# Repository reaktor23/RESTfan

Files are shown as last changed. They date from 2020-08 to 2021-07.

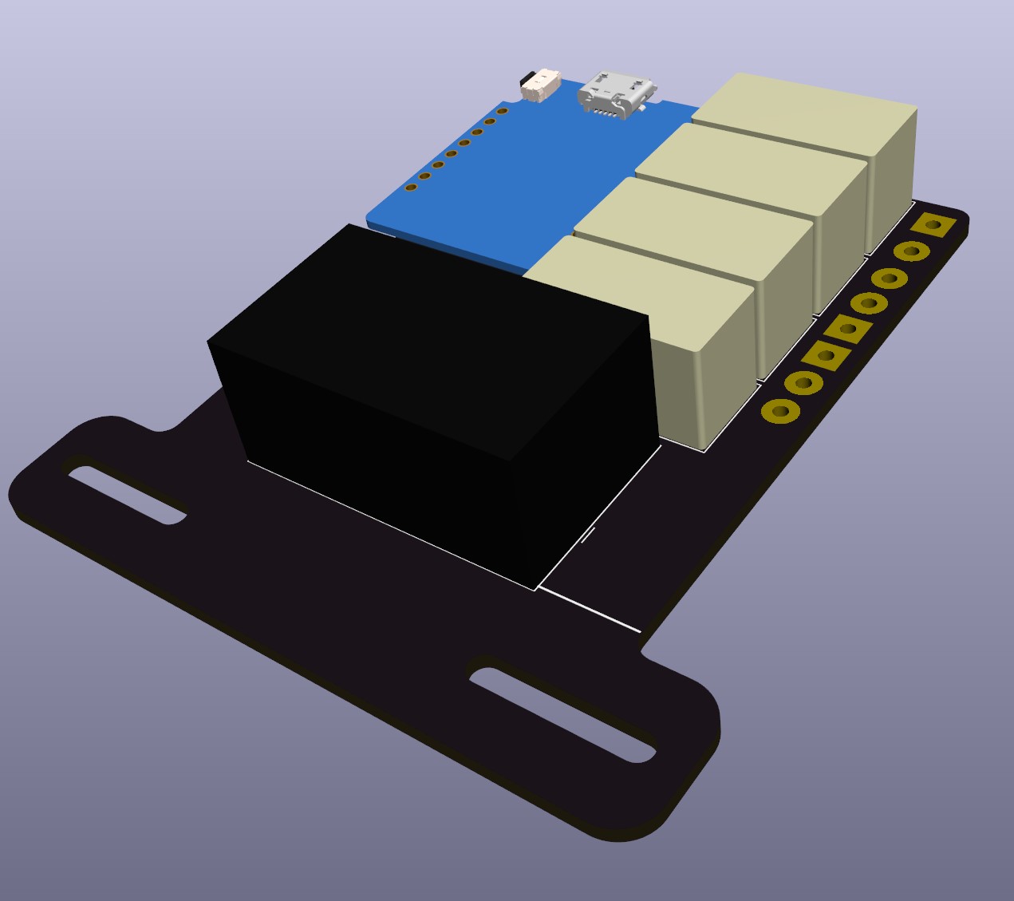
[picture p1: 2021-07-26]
Top.jpg

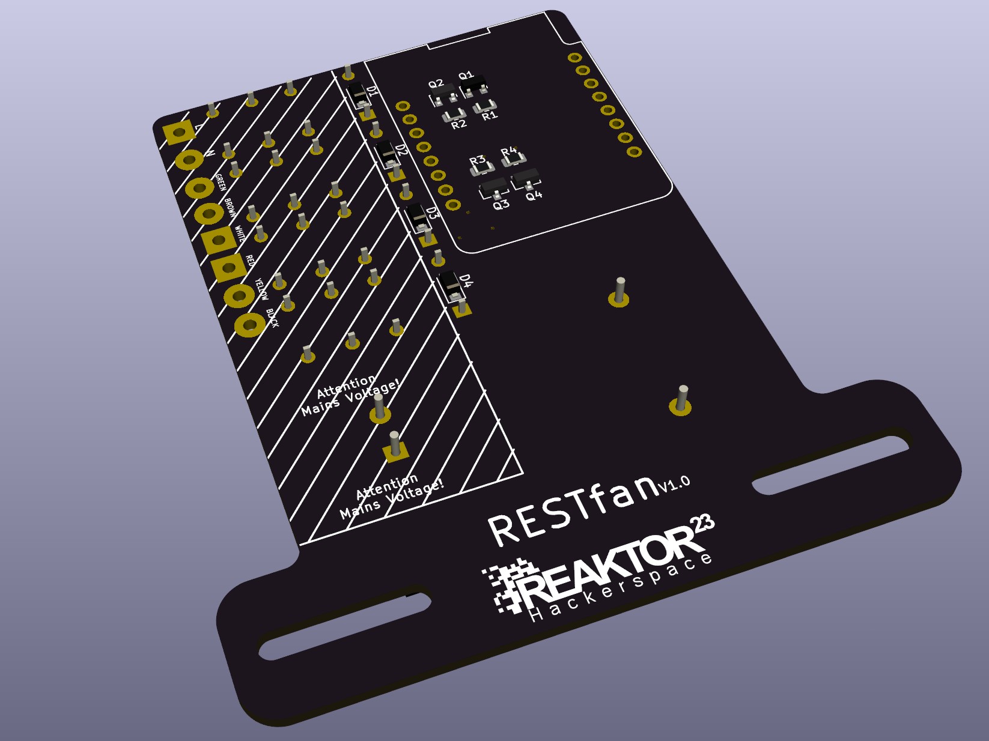
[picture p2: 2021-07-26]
Bottom.jpg

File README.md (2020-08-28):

# RESTfan

A REST controllable wall fan

We bought a cheap wall mount fan which had pull strings for control. Big no no for a Hackerspace :sunglasses:

So we created a small PCB with a 230VAC to 5VDC converter, a Wemos D1 mini and 4 relays on it that allows us to control the fan over a REST API.

# Hardware

The fan is a [Tristar VE-5874 wall mount ventilator](https://www.tristar.eu/de-de/tristar-ve-5874-wandventilator-ve--5874)

# API

- `http://<ip>/off` Fan and oscillation off
- `http://<ip>/state` JSON object with the current state

## Speed control

 - `http://<ip>/speed/1` Fan speed 1
 - `http://<ip>/speed/2` Fan speed 2
 - `http://<ip>/speed/3` Fan speed 3

## Oscillation

 - `http://<ip>/oscillation/on` Oscillation on
 - `http://<ip>/oscillation/off` Oscillation off

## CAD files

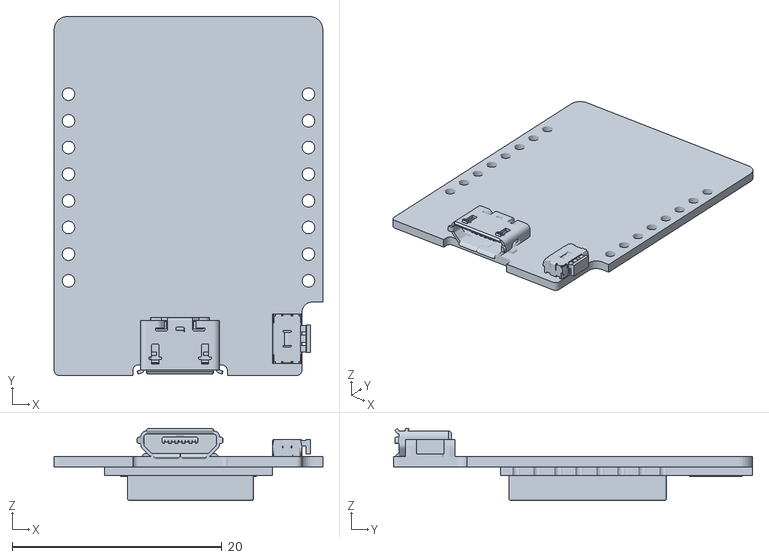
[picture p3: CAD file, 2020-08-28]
KiCAD/RESTfan/3Dshapes/wemos d1 mini.stl
25.6 x 34.2 x 6.90

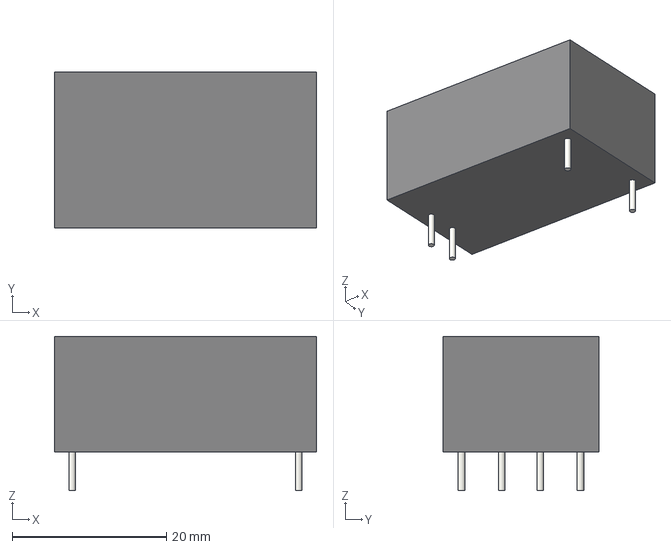
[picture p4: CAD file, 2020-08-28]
KiCAD/RESTfan/3Dshapes/Converter_ACDC_HiLink_HLK-PMxx.step
34.0 x 20.2 x 20.0 mm

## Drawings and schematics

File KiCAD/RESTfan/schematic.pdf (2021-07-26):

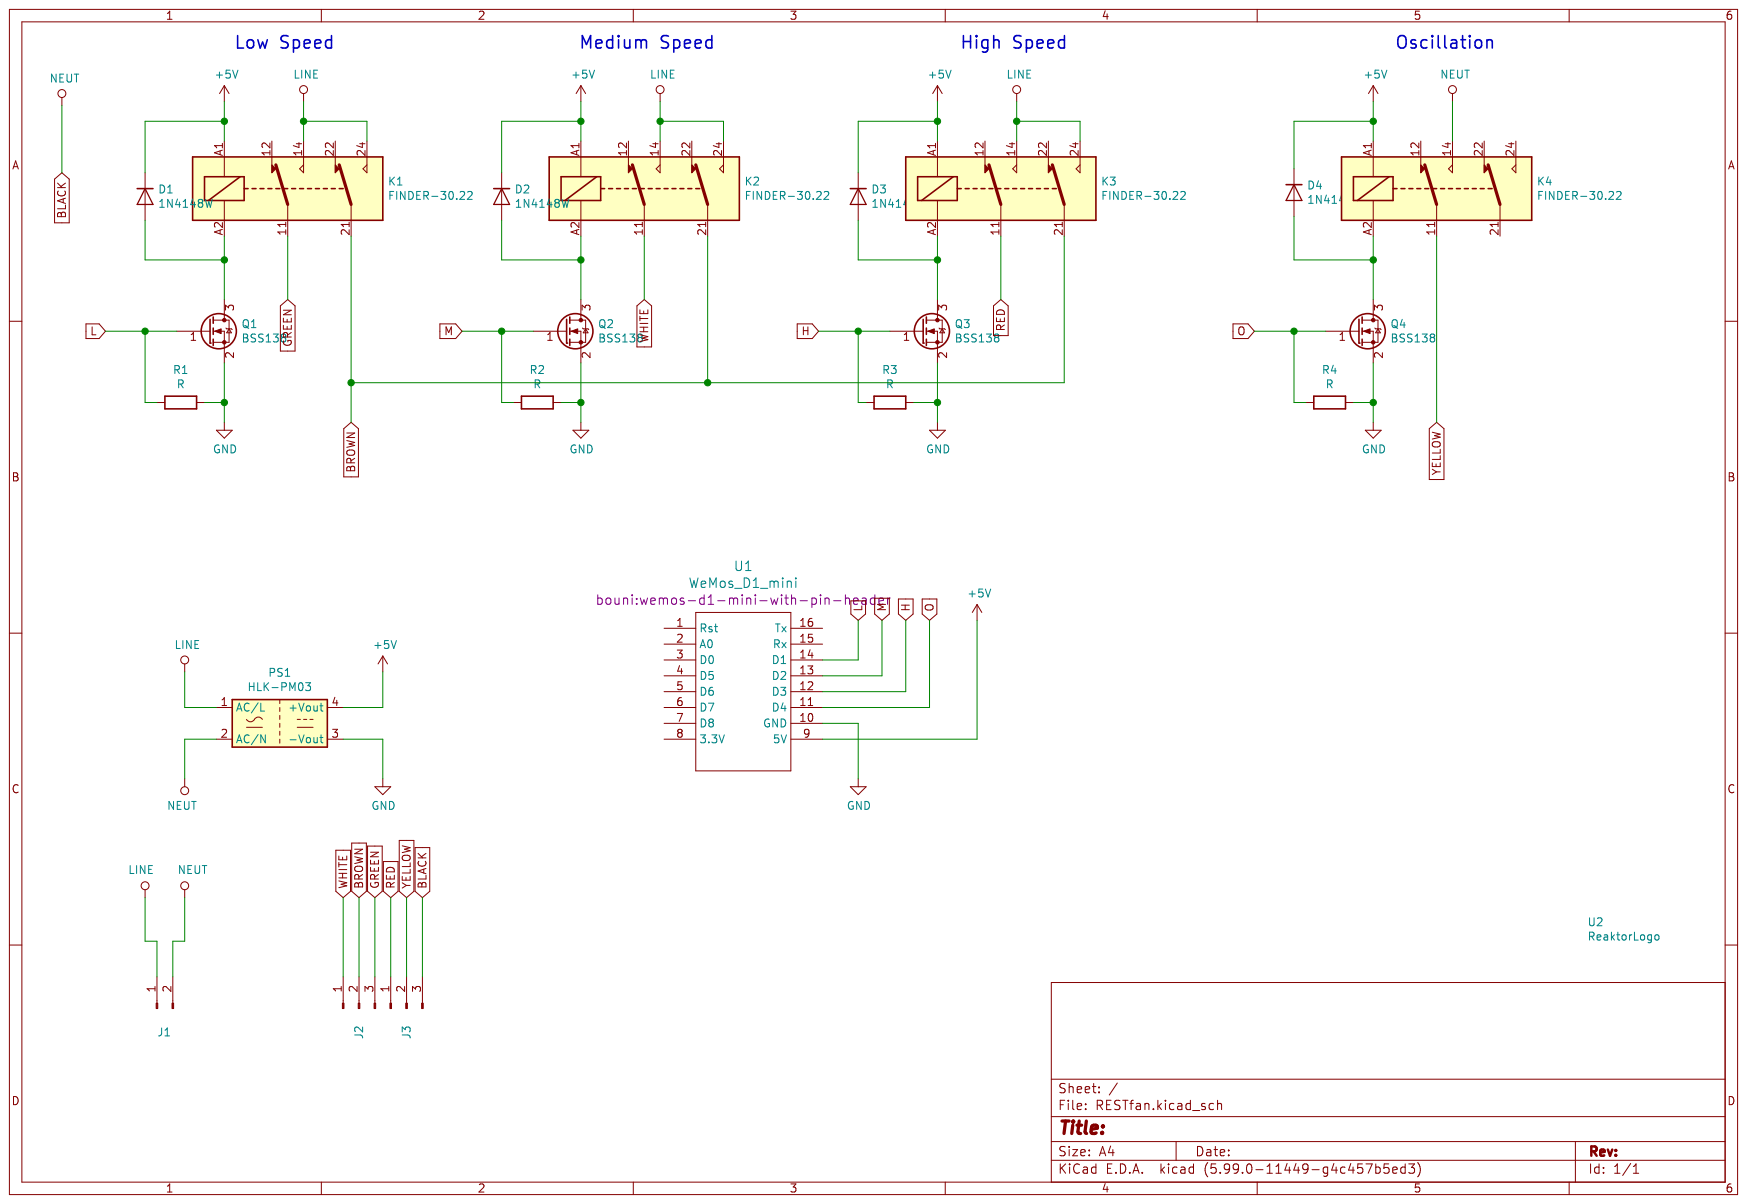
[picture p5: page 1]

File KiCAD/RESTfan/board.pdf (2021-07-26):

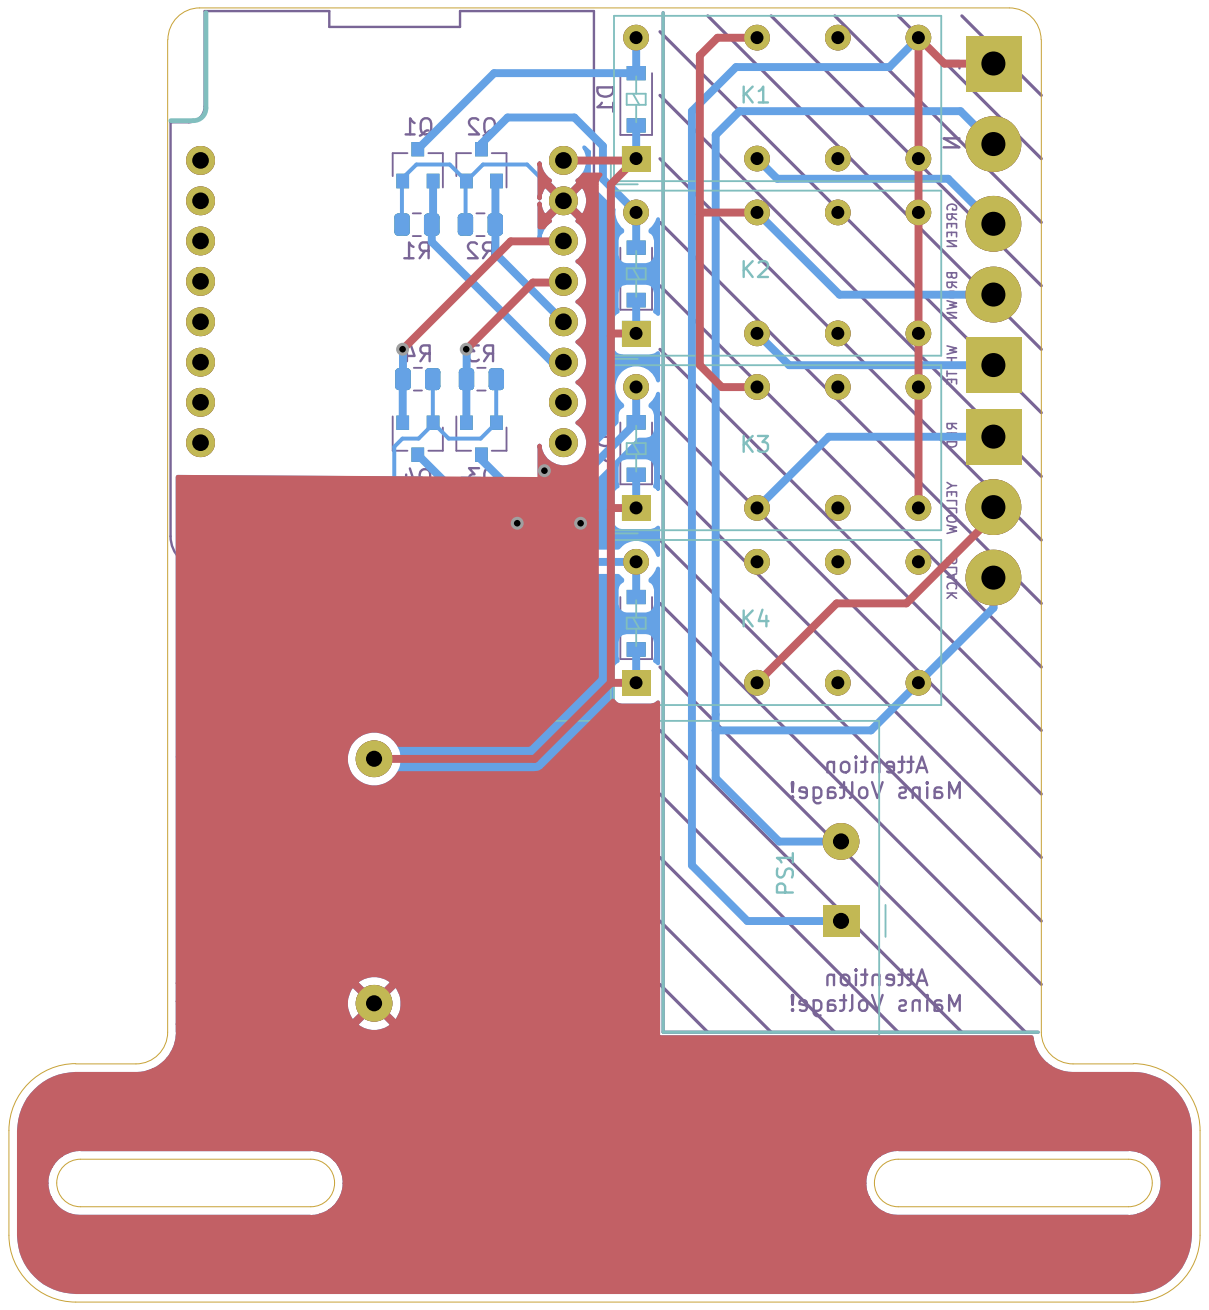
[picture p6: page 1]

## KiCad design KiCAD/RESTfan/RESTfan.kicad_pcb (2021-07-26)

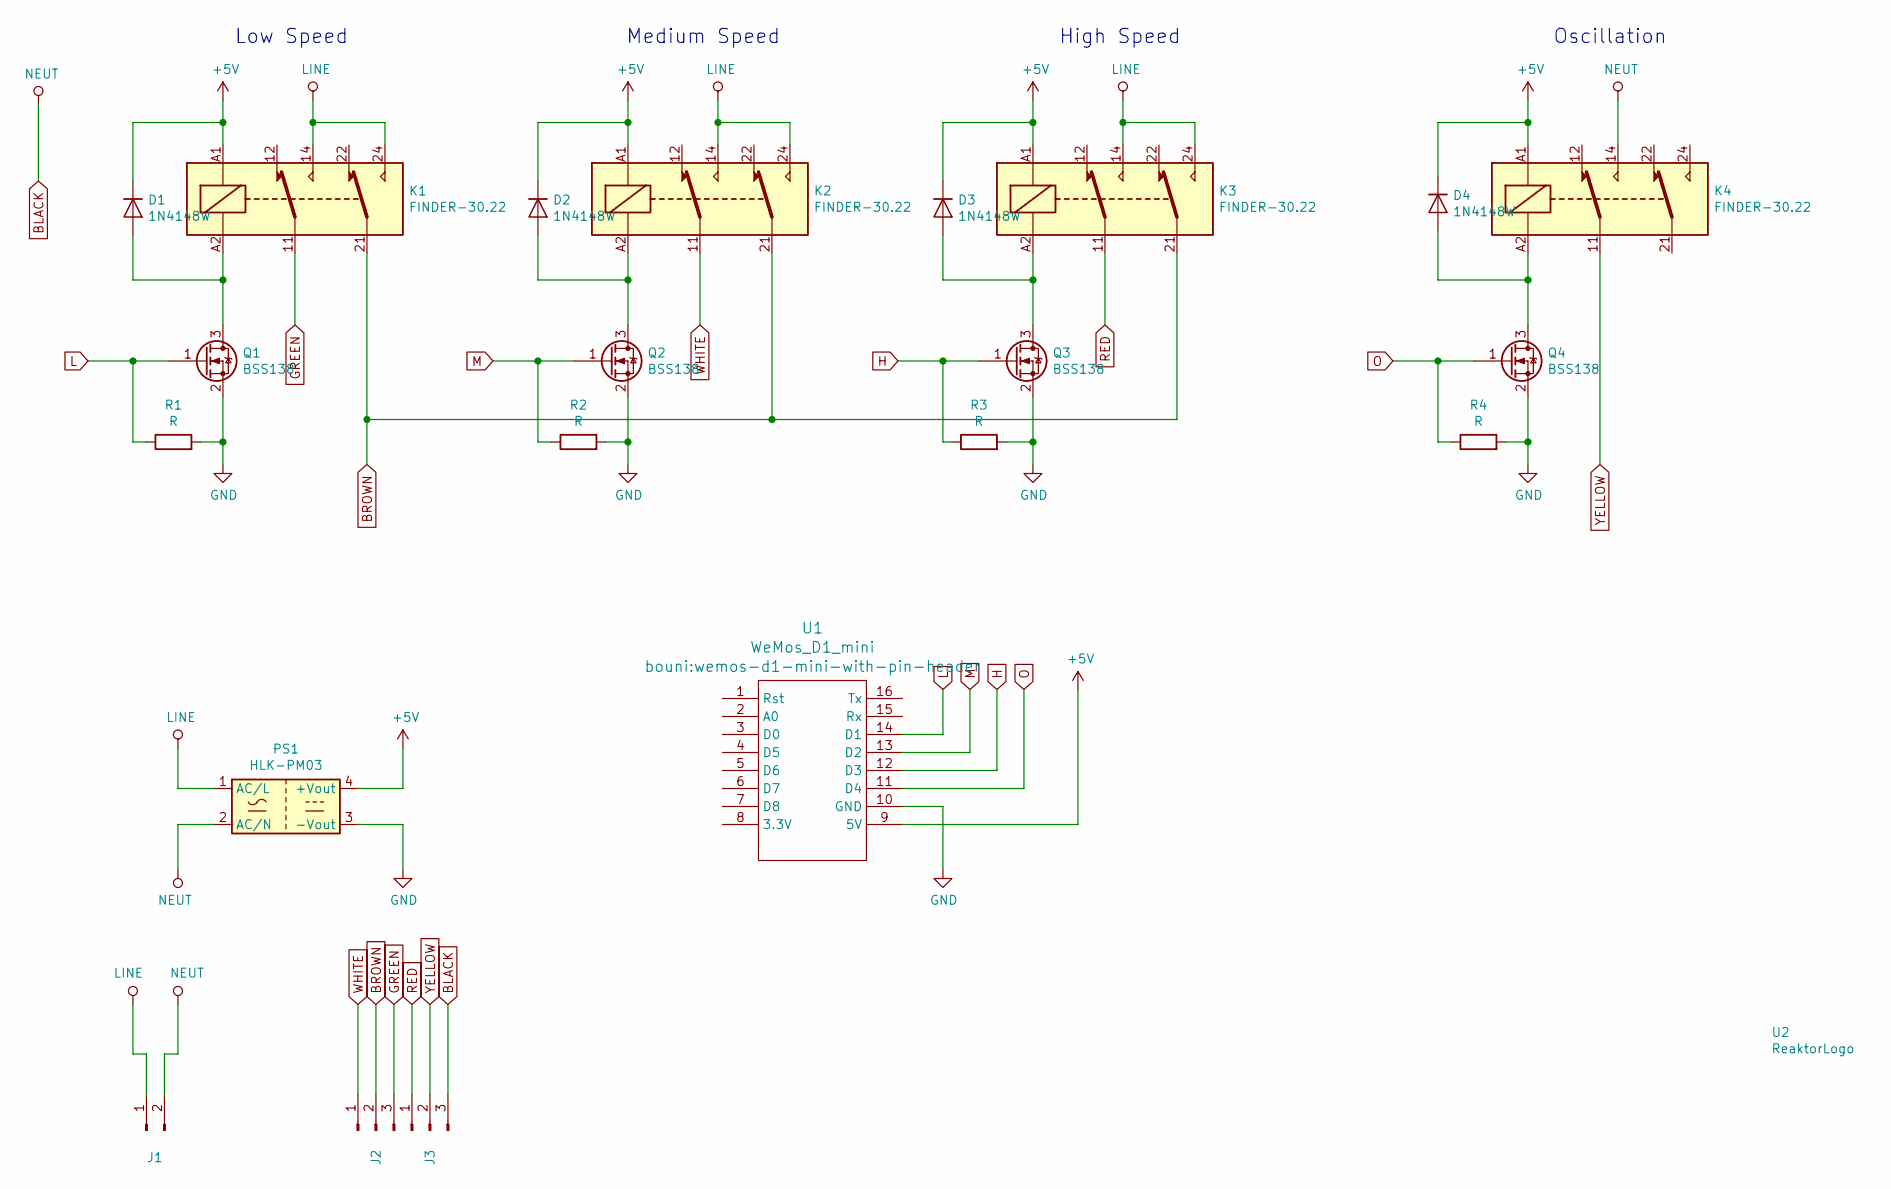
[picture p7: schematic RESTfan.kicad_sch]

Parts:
D1, D2, D3, D4: 1N4148W; D_SOD-123
J1: Conn_01x02_Male; SolderWirePad_1x02_P5.08mm_Drill1.5mm
J2, J3: Conn_01x03_Male; SolderWirePad_1x03_P4.445mm_Drill1.5mm
K1, K2, K3, K4: FINDER-30.22; Relay_DPDT_Finder_30.22
PS1: HLK-PM03; Converter_ACDC_HiLink_HLK-PMxx
Q1, Q2, Q3, Q4: BSS138; SOT-23
R1, R2, R3, R4: R; R_0805_2012Metric
U1: WeMos_D1_mini; wemos-d1-mini-with-pin-header
U2: ReaktorLogo; Reaktor23_8mm

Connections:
+5V: D1.1 (K), D2.1 (K), D3.1 (K), D4.1 (K), K1.A1, K2.A1, K3.A1, K4.A1, PS1.4 (+Vout), U1.9 (5V)
BLACK: J1.2, J3.3, K4.14, PS1.2 (AC/N)
BROWN: J2.2, K1.21, K2.21, K3.21
GND: PS1.3 (-Vout), Q1.2 (S), Q2.2 (S), Q3.2 (S), Q4.2 (S), R1.2, R2.2, R3.2, R4.2, U1.10 (GND)
GREEN: J2.3, K1.11
H: Q3.1 (G), R3.1, U1.12 (D3)
L: Q1.1 (G), R1.1, U1.14 (D1)
LINE: J1.1, K1.14, K1.24, K2.14, K2.24, K3.14, K3.24, PS1.1 (AC/L)
M: Q2.1 (G), R2.1, U1.13 (D2)
unnamed: D1.2 (A), K1.A2, Q1.3 (D)
unnamed: D2.2 (A), K2.A2, Q2.3 (D)
unnamed: D3.2 (A), K3.A2, Q3.3 (D)
unnamed: D4.2 (A), K4.A2, Q4.3 (D)
O: Q4.1 (G), R4.1, U1.11 (D4)
RED: J3.1, K3.11
WHITE: J2.1, K2.11
YELLOW: J3.2, K4.11

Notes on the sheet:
Low Speed
Medium Speed
High Speed
Oscillation

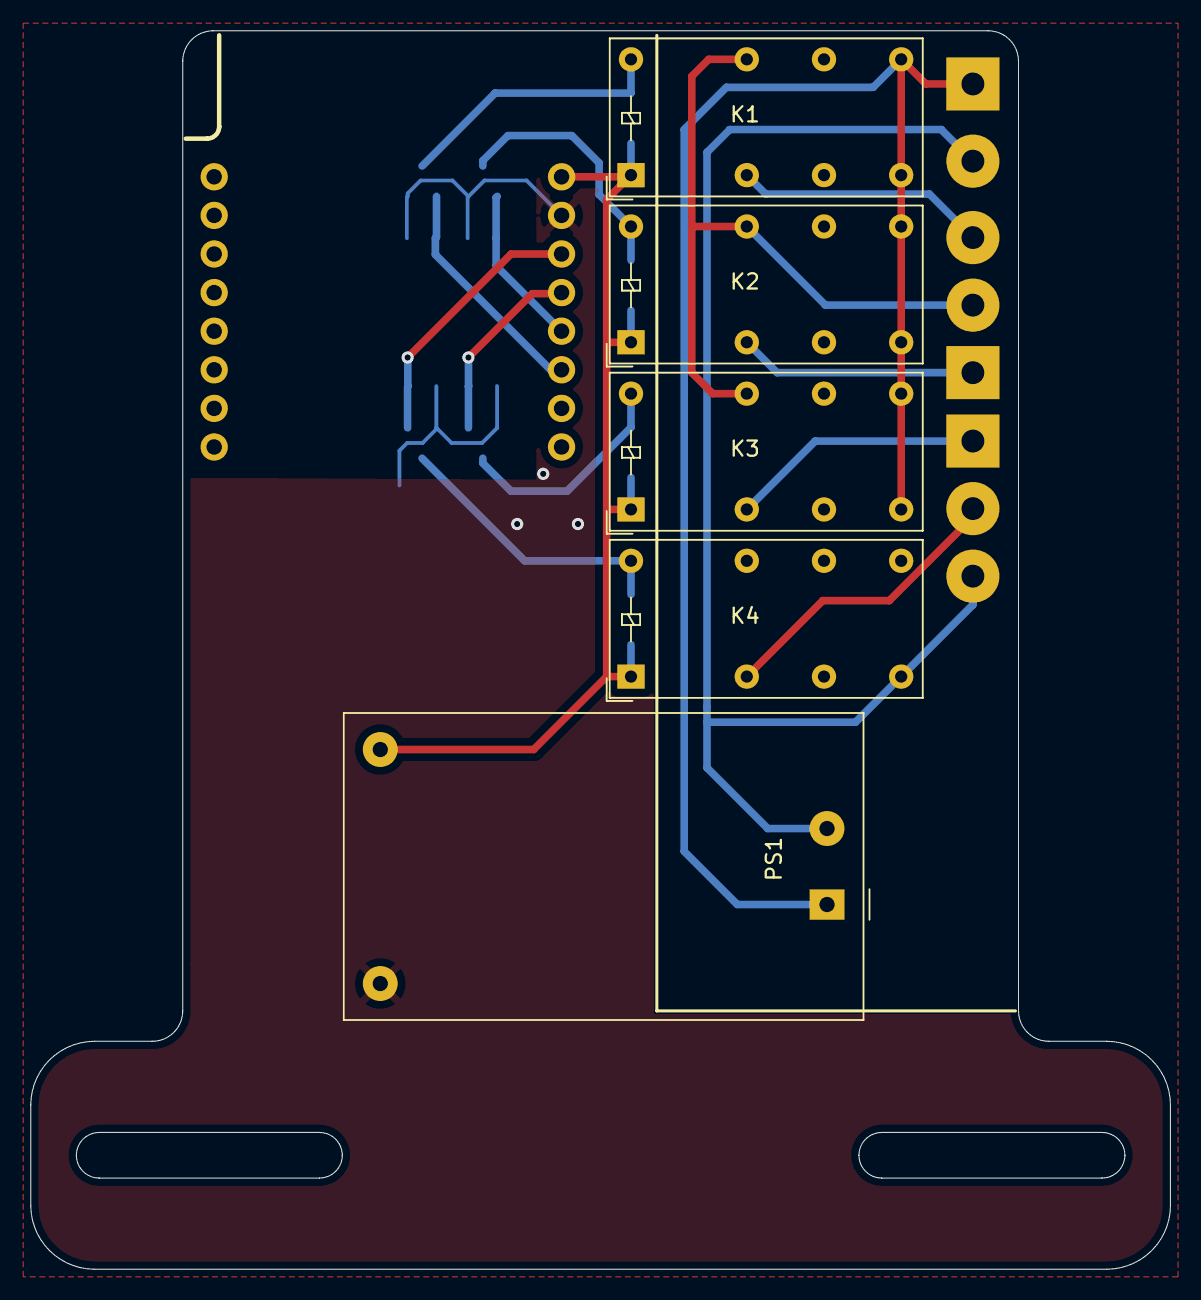
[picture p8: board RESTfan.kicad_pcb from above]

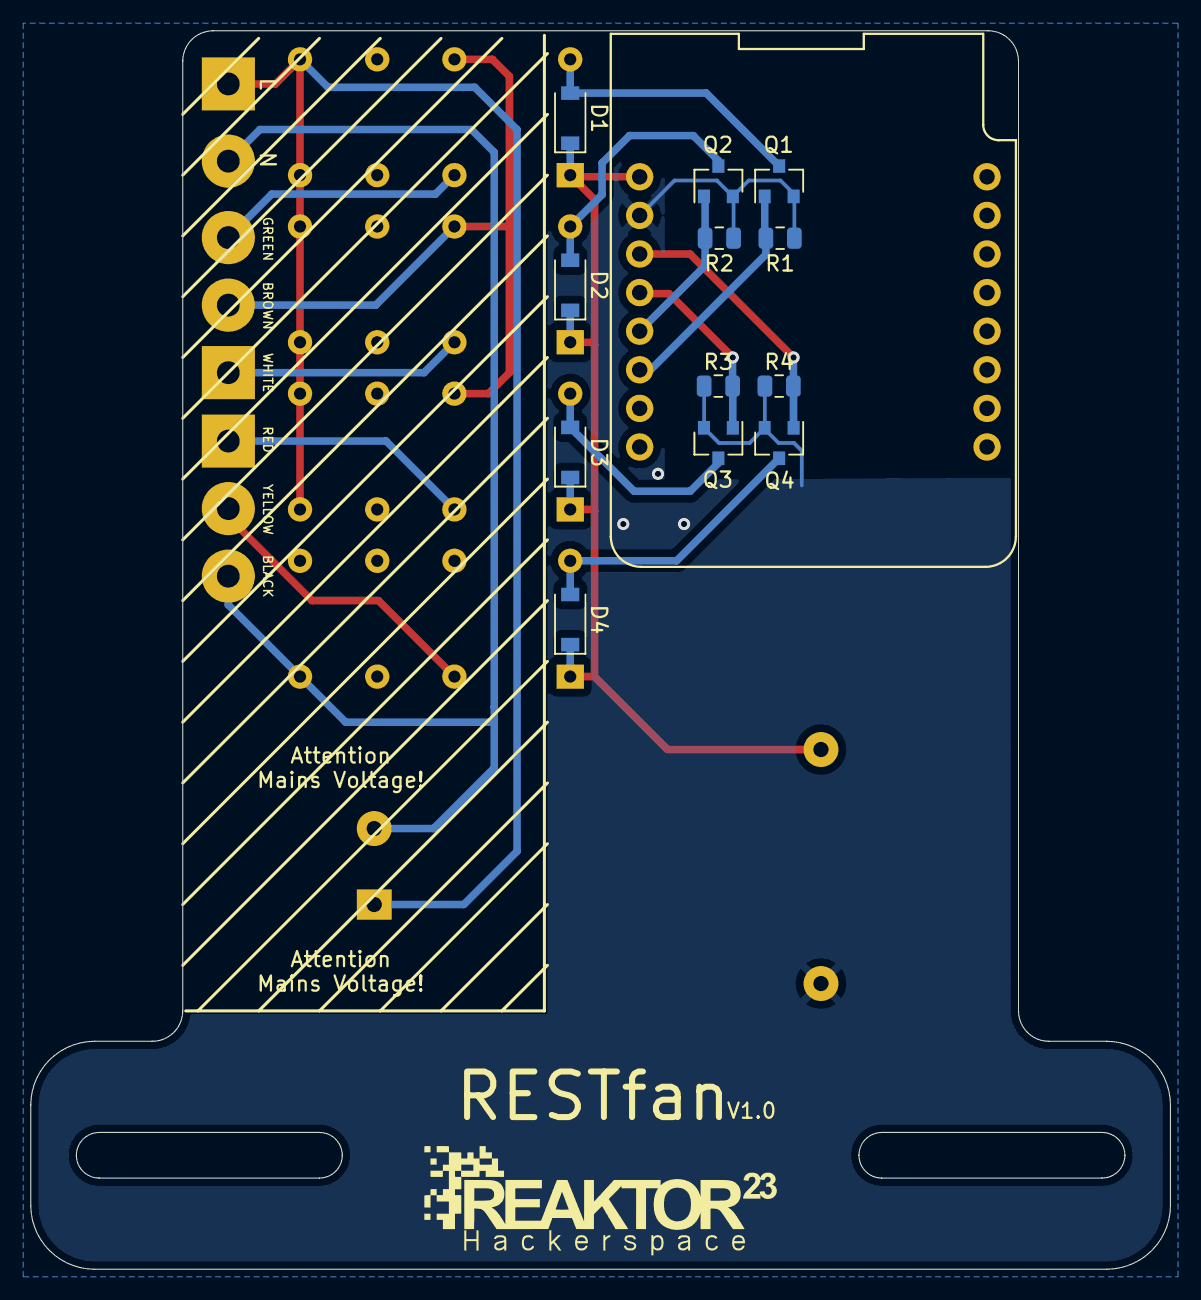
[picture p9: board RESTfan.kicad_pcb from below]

Board: 2 copper layers, 75.0 x 81.5 mm, 22 parts (14 on the bottom side), 17 nets.

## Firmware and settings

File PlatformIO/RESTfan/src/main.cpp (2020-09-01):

#include <stdio.h>
#include <ESP8266WebServer.h>
#include <ArduinoJson.h>
#include "secret.h"

#define HTTP_REST_PORT 80
#define WIFI_RETRY_DELAY 500
#define MAX_WIFI_INIT_RETRY 50

#define FAN_SPEED_1 5
#define FAN_SPEED_2 4
#define FAN_SPEED_3 0
#define OSCILLATION 2

//const char* wifi_ssid = "reaktor23";
//const char* wifi_passwd = "highsecuritypassword";

ESP8266WebServer http_rest_server(HTTP_REST_PORT);

int speed = 0;
bool oscillation = false;

int init_wifi() {
    int retries = 0;

    Serial.println("Connecting to WiFi AP..........");

    WiFi.mode(WIFI_STA);
    WiFi.begin(wifi_ssid, wifi_passwd);
    // check the status of WiFi connection to be WL_CONNECTED
    while ((WiFi.status() != WL_CONNECTED) && (retries < MAX_WIFI_INIT_RETRY)) {
        retries++;
        delay(WIFI_RETRY_DELAY);
        Serial.print("#");
    }
    return WiFi.status(); // return the WiFi connection status
}

void send_state() {
    StaticJsonDocument<200> doc;
    char JSONmessageBuffer[200];
    doc["speed"] = speed;
    doc["oscillation"] = oscillation;
    serializeJsonPretty(doc, JSONmessageBuffer);
    http_rest_server.send(200, "application/json", JSONmessageBuffer);
}


void init_relays() {
    pinMode(FAN_SPEED_1, OUTPUT);
    pinMode(FAN_SPEED_2, OUTPUT);
    pinMode(FAN_SPEED_3, OUTPUT);
    pinMode(OSCILLATION, OUTPUT);
    digitalWrite(FAN_SPEED_1, LOW);
    digitalWrite(FAN_SPEED_2, LOW);
    digitalWrite(FAN_SPEED_3, LOW);
    digitalWrite(OSCILLATION, LOW);
    delay(100);
}

void off() {
    digitalWrite(FAN_SPEED_1, LOW);
    digitalWrite(FAN_SPEED_2, LOW);
    digitalWrite(FAN_SPEED_3, LOW);
    digitalWrite(OSCILLATION, LOW);
    speed = 0;
    oscillation = false;
    send_state();
    delay(100);
}

void speed_1() {
    digitalWrite(FAN_SPEED_2, LOW);
    digitalWrite(FAN_SPEED_3, LOW);
    delay(100);
    digitalWrite(FAN_SPEED_1, HIGH);
    speed = 1;
    send_state();
    delay(100);
}

void speed_2() {
    digitalWrite(FAN_SPEED_1, LOW);
    digitalWrite(FAN_SPEED_3, LOW);
    delay(100);
    digitalWrite(FAN_SPEED_2, HIGH);
    speed = 2;
    send_state();
    delay(100);
}

void speed_3() {
    digitalWrite(FAN_SPEED_1, LOW);
    digitalWrite(FAN_SPEED_2, LOW);
    delay(100);
    digitalWrite(FAN_SPEED_3, HIGH);
    speed = 3;
    send_state();
    delay(100);
}

void oscillation_on() {
    digitalWrite(OSCILLATION, HIGH);
    oscillation = true;
    send_state();
    delay(100);
}

void oscillation_off() {
    digitalWrite(OSCILLATION, LOW);
    oscillation = false;
    send_state();
    delay(100);
}

void config_rest_server_routing() {
    http_rest_server.on("/", HTTP_GET, []() {
        http_rest_server.send(200, "text/html",
            "Welcome to RESTfan");
    });
    http_rest_server.on("/state", HTTP_GET, send_state);
    /*
    http_rest_server.on("/off", HTTP_GET, off);
    http_rest_server.on("/speed/1", HTTP_GET, speed_1);
    http_rest_server.on("/speed/2", HTTP_GET, speed_2);
    http_rest_server.on("/speed/3", HTTP_GET, speed_3);
    http_rest_server.on("/oscillation/on", HTTP_GET, oscillation_on);
    http_rest_server.on("/oscillation/off", HTTP_GET, oscillation_off);
    */
    http_rest_server.on("/off", HTTP_POST, off);
    http_rest_server.on("/speed/1", HTTP_POST, speed_1);
    http_rest_server.on("/speed/2", HTTP_POST, speed_2);
    http_rest_server.on("/speed/3", HTTP_POST, speed_3);
    http_rest_server.on("/oscillation/on", HTTP_POST, oscillation_on);
    http_rest_server.on("/oscillation/off", HTTP_POST, oscillation_off);
}

void setup(void) {
    init_relays();

    Serial.begin(115200);

    if (init_wifi() == WL_CONNECTED) {
        Serial.print("Connected to ");
        Serial.print(wifi_ssid);
        Serial.print("--- IP: ");
        Serial.println(WiFi.localIP());
    }
    else {
        Serial.print("Error connecting to: ");
        Serial.println(wifi_ssid);
    }

    config_rest_server_routing();

    http_rest_server.begin();
    Serial.println("HTTP REST Server Started");
}

void loop(void) {
    http_rest_server.handleClient();
}
